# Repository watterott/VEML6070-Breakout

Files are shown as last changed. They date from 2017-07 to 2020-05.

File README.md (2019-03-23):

# VEML6070-Breakout
Breakout with Vishay VEML6070 digital UV Light Sensor.

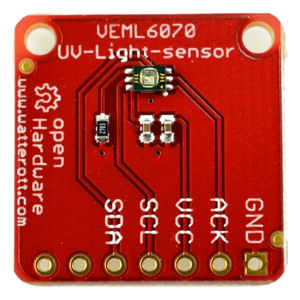
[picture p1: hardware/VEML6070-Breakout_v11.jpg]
VEML6070-Breakout


* [Vishay VEML6070](https://www.vishay.com/docs/84277/veml6070.pdf) Light Sensor
* Detects UV light
* TWI/I2C Interface (address 0x38 and 0x39)
* 3.3V - 5V Power Supply and Logic Level
* Open-Source and released under the [Creative Commons Attribution Share-Alike License](https://creativecommons.org/licenses/by-sa/4.0/).
* **[Documentation on learn.watterott.com](https://learn.watterott.com)**

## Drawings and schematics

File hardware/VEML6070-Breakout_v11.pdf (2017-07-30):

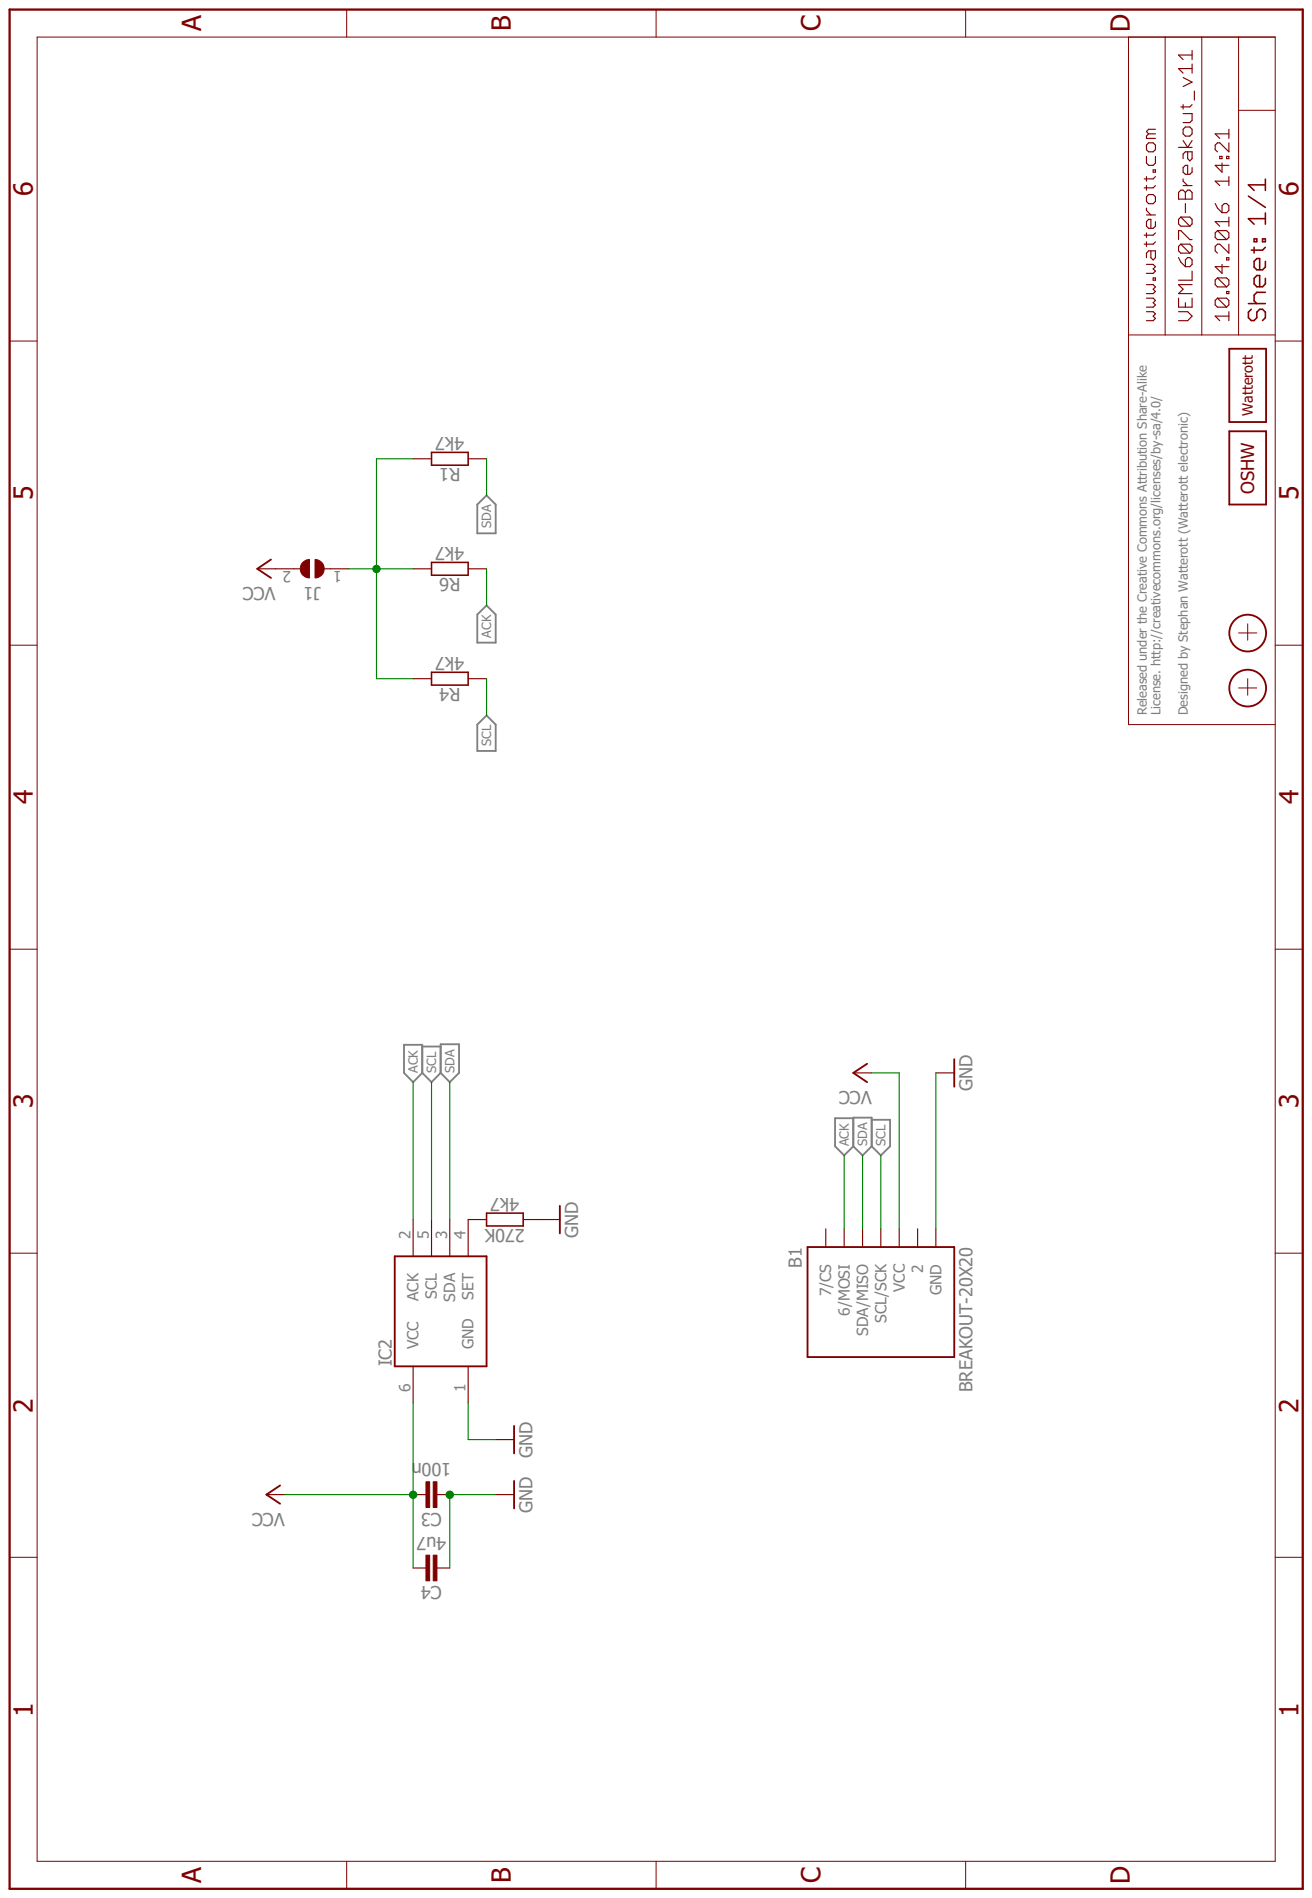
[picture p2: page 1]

GND GND GND CCV n0017k4 7k4 7k4 7k4 GND 7u4 CCV CCV Released under the Creative Commons Attribution Share-Alike License. http://creativecommons.org/licenses/by-sa/4.0/ Designed by Stephan Watterott (Watterott electronic) 3C1R4R6RGND 1 ACK 2 SDA 3 SET 4 SCL 5 VCC 6 IC2 K072 4C 1J 2 1 B1 BREAKOUT-20X20 6/MOSI SDA/MISO SCL/SCK VCC2 GND 7/CS SCL SCL SCL SDA SDA SDA ACK ACK ACK ABCD 1 2 3 4 5 6 ABCD 1 2 3 4 5 6 Watterott OSHW

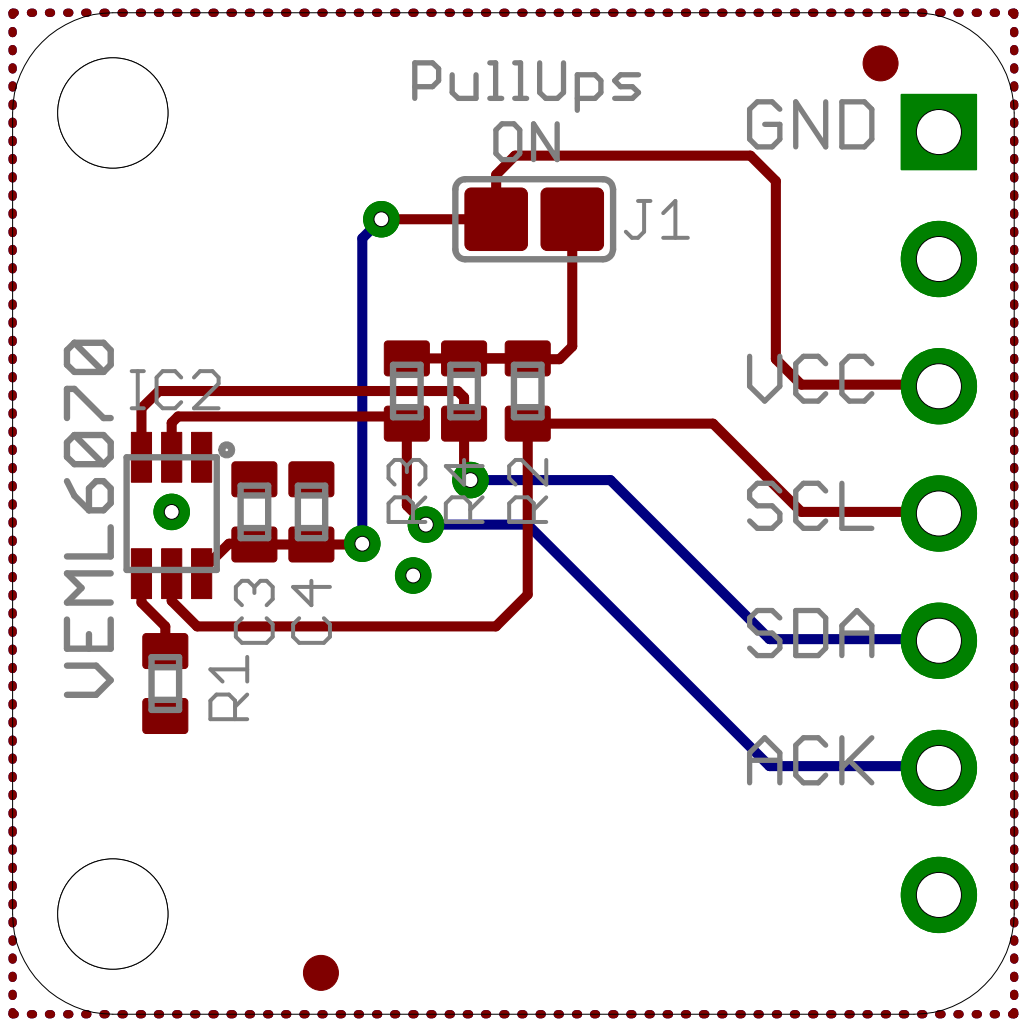
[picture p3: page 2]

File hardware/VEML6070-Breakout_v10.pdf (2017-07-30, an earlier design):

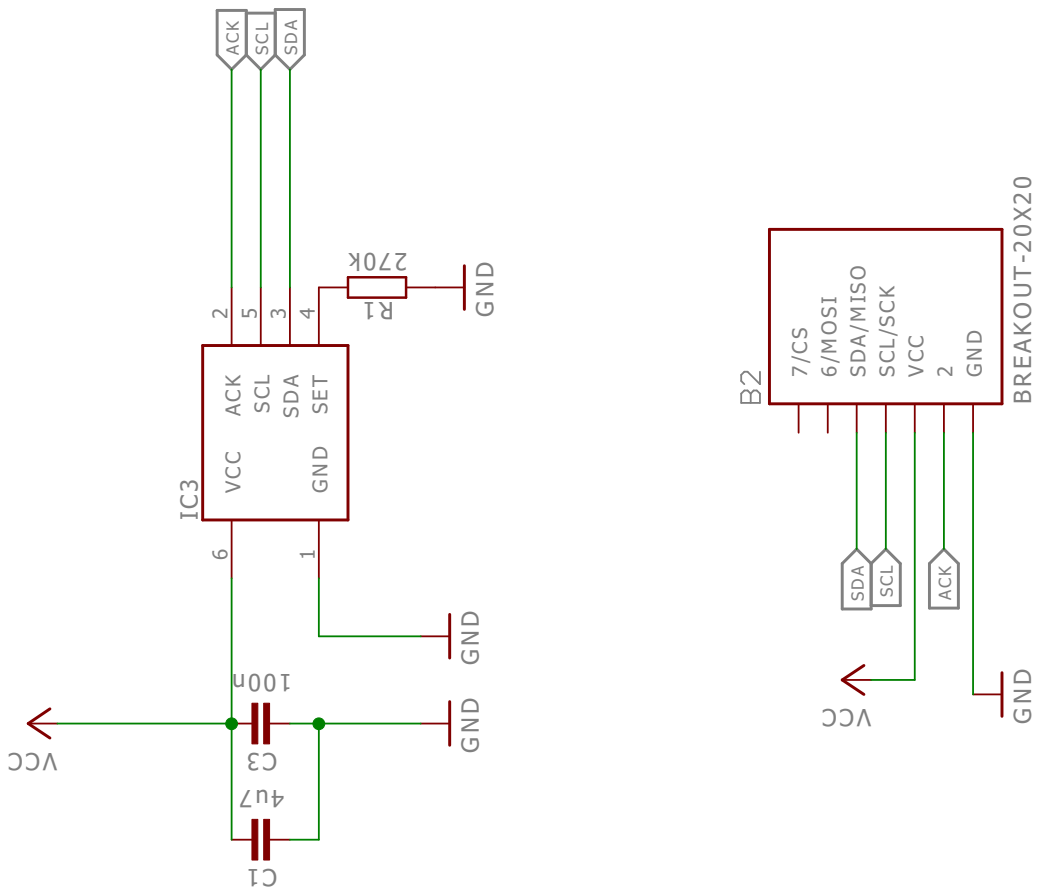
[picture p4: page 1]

GND GNDGND CCV n001 k 072 CCV 7u4 GND Released under the Creative Commons Attribution Share-Alike License http://creativecommons.org/licenses/by-sa/4.0/ Designed by Stephan W atterott (W atterott electronic) 3 C 1 R GND 1 ACK 2 SDA 3 SET 4 SCL 5 VCC 6 IC3 1 C BREAKOUT-20X20 6/MOSI SDA/MISO SCL/SCK VCC 2GND 7/CS SCL SCL SDA SDA ACK ACK ABCD 1 2 3 4 5 6 ABCD 1 2 3 4 5 6 OSHW

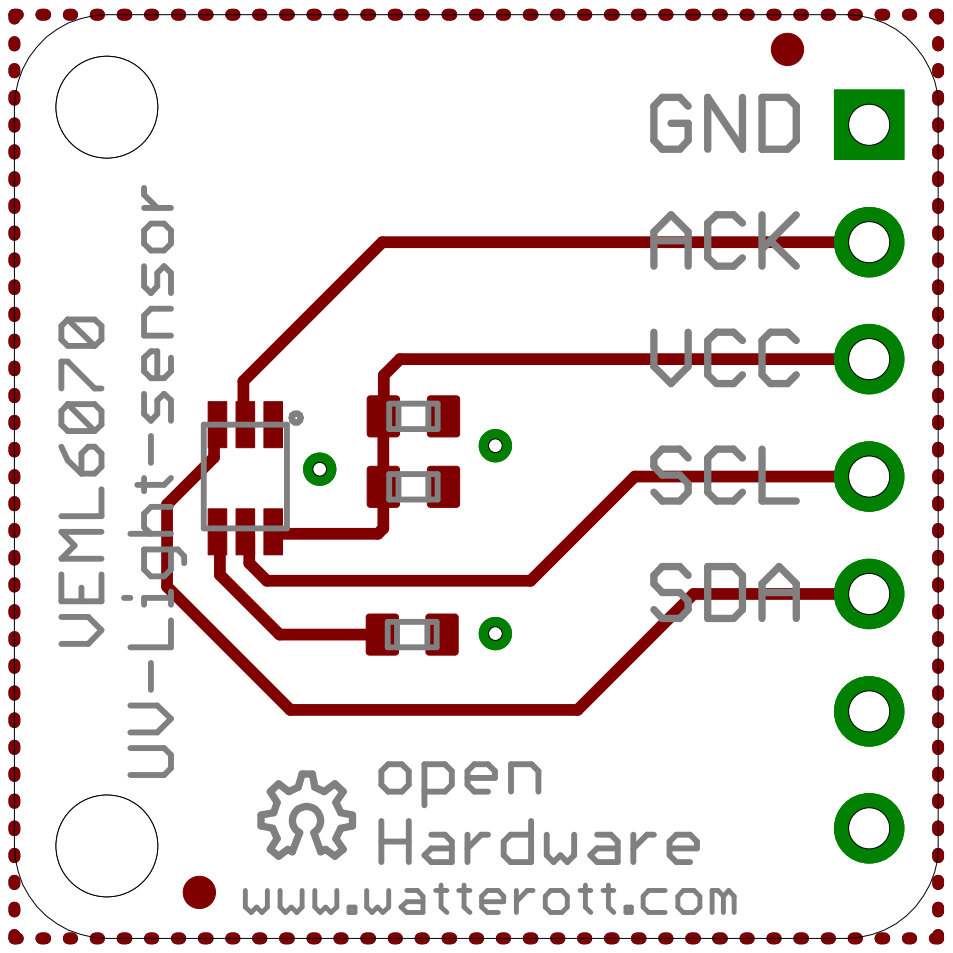
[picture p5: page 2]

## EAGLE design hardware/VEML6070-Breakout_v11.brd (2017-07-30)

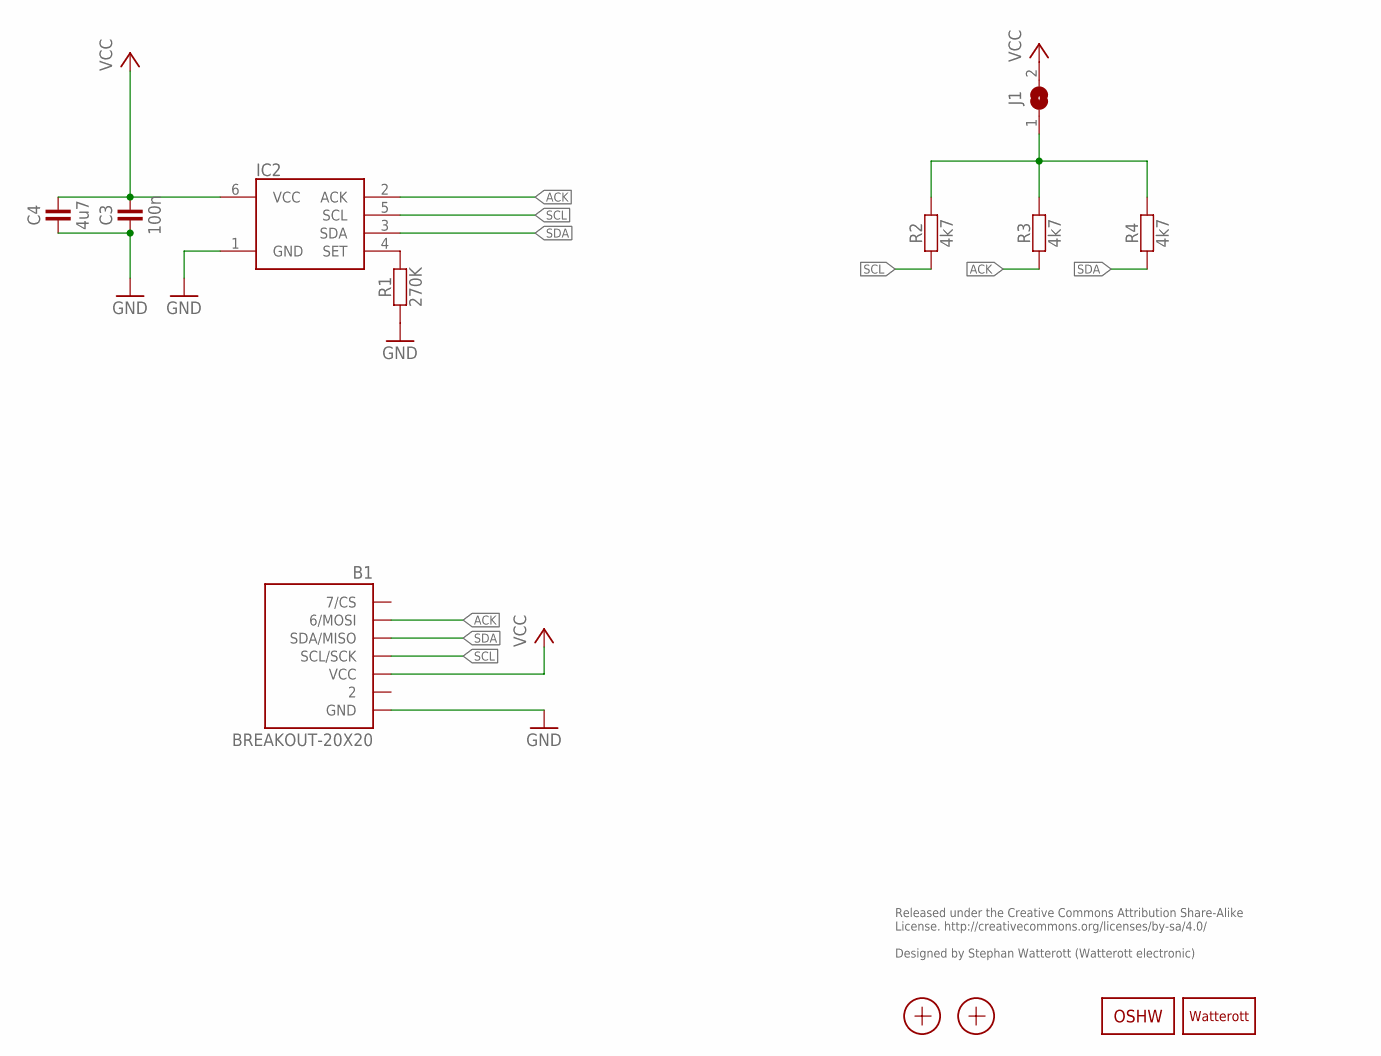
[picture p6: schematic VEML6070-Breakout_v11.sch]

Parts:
B1: BREAKOUT-20X20
C3: 100n; R0402
C4: 4u7; R0402
IC2: VEML6070; OPLGA
J1: JUMPER2-0603-NC; JUMPER2-0603_NC
LOGO1: LOGO-S_PLACE_M; SPARK_TPLACE_M
LOGO2: OSHW_LOGOX0070; OSHW_6X70
R1: 270K; R0402
R2, R3, R4: 4k7; R0402
X1, X2: PASSER-07; PASSER_07MM

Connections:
ACK: B1.MOSI (6/MOSI), IC2.2 (ACK), R3.1
GND: B1.GND, C3.1, C4.1, IC2.1 (GND), R1.1
unnamed: IC2.4 (SET), R1.2
unnamed: J1.1, R2.2, R3.2, R4.2
SCL: B1.SCL/SCK, IC2.5 (SCL), R2.1
SDA: B1.SDA/MISO, IC2.3 (SDA), R4.1
VCC: B1.VCC, C3.2, C4.2, IC2.6 (VCC), J1.2

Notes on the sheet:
Released under the Creative Commons Attribution Share-Alike License. http://creativecommons.org/licenses/by-sa/4.0/ Designed by Stephan Watterott (Watterott electronic)

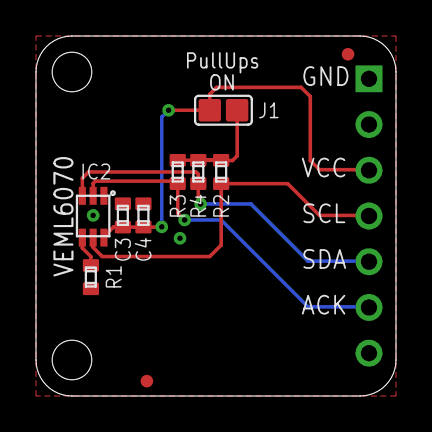
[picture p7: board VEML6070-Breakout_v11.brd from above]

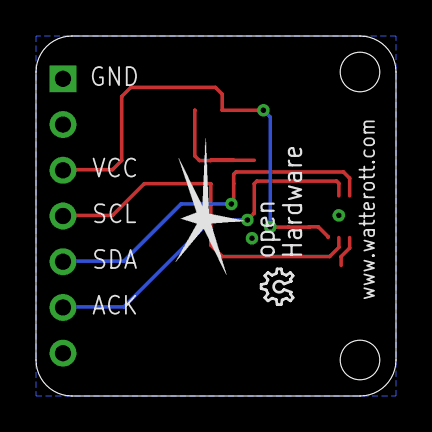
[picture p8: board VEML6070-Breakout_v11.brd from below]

Board: 2 copper layers, 20.0 x 20.0 mm, 13 parts (2 on the bottom side), 7 nets.

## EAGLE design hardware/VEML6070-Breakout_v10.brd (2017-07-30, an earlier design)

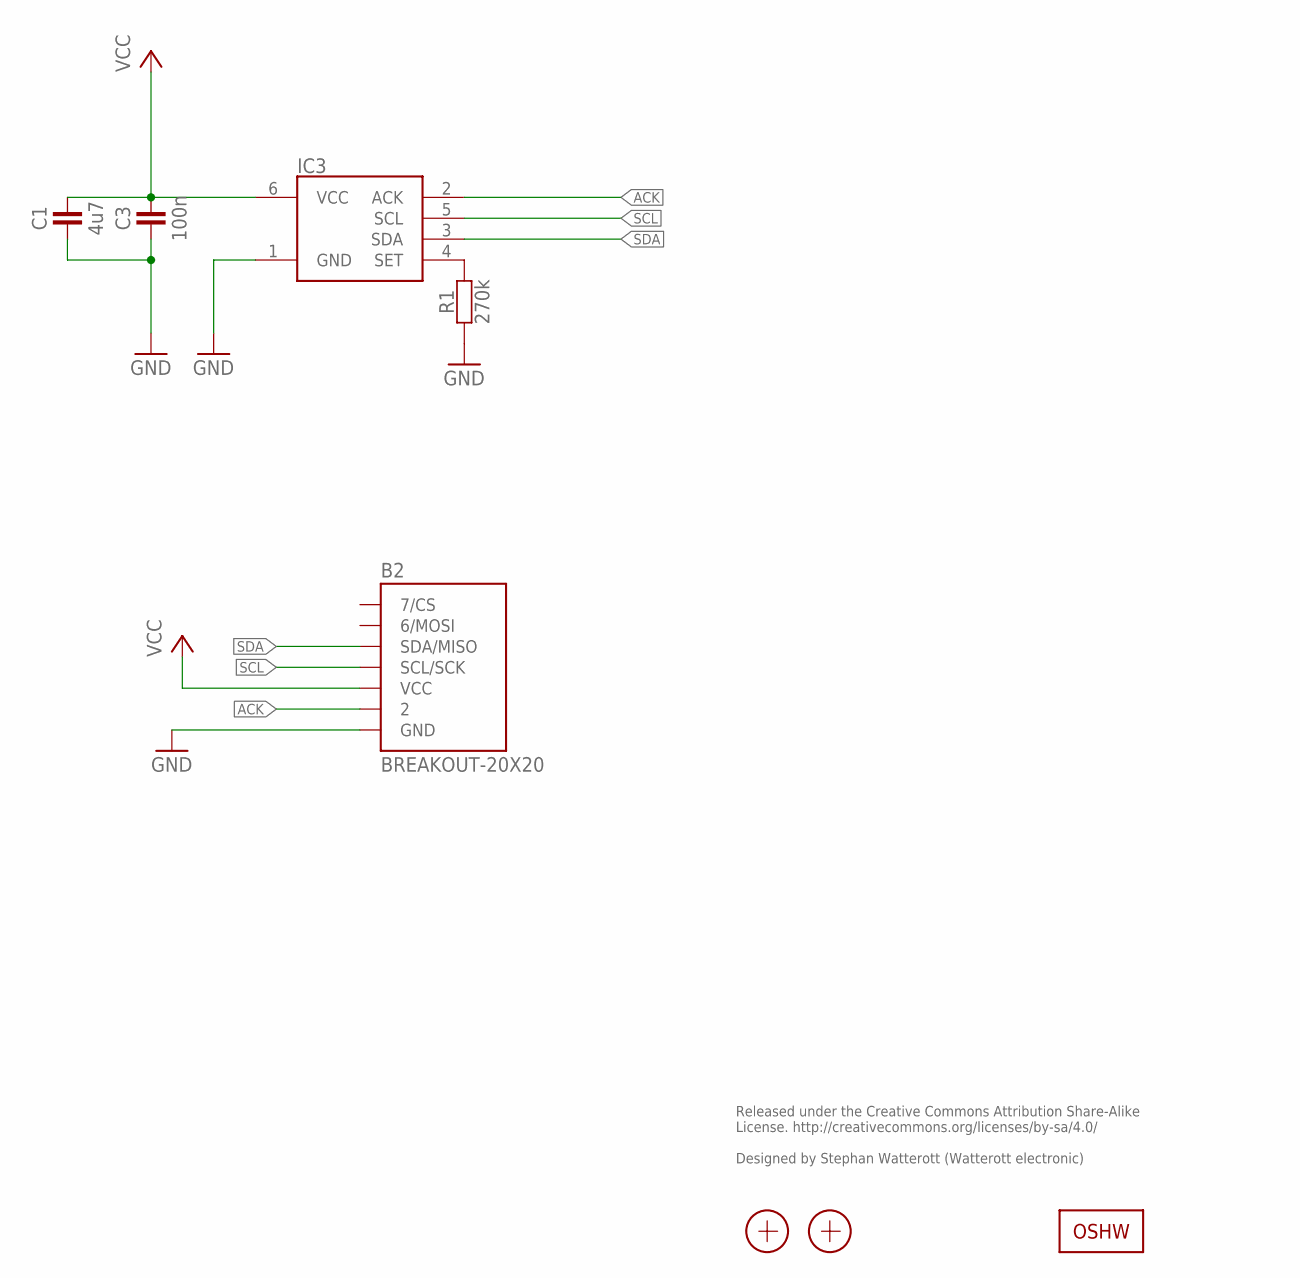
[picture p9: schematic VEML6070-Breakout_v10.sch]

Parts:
B2: BREAKOUT-20X20
C1: 4u7; R0402
C3: 100n; R0402
IC3: VEML6070; OPLGA
LOGO2: OSHW_LOGOX0070; OSHW_6X70
R1: 270k; R0402
X1, X2: PASSER-07; PASSER_07MM

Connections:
ACK: B2.2, IC3.2 (ACK)
GND: B2.GND, C1.1, C3.1, IC3.1 (GND), R1.1
unnamed: IC3.4 (SET), R1.2
SCL: B2.SCL/SCK, IC3.5 (SCL)
SDA: B2.SDA/MISO, IC3.3 (SDA)
VCC: B2.VCC, C1.2, C3.2, IC3.6 (VCC)

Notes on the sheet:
Released under the Creative Commons Attribution Share-Alike License. http://creativecommons.org/licenses/by-sa/4.0/ Designed by Stephan Watterott (Watterott electronic)

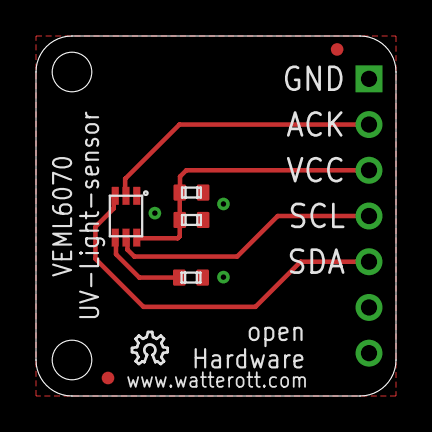
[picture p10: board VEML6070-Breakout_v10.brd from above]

Board: 2 copper layers, 20.0 x 20.0 mm, 8 parts (0 on the bottom side), 6 nets.

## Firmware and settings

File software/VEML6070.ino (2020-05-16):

/*
  Example sketch for VEML6070-Breakout (Digital UV Light Sensor).
  Rset=270k on breakout, UVA sensitivity: 5.625 uW/cm²/step

  Board           I2C/TWI Pins
                  SDA, SCL
  ----------------------------
  Uno, Ethernet    A4, A5
  Mega             20, 21
  Leonardo          2,  3
  Due              20, 21

  Integration Times and UVA Sensitivity:
    Rset=240k -> 1T=100.0ms ->   5.000 uW/cm²/step
    Rset=270k -> 1T=112.5ms ->   5.625 uW/cm²/step
    Rset=300k -> 1T=125.0ms ->   6.250 uW/cm²/step
    Rset=600k -> 1T=250.0ms ->  12.500 uW/cm²/step

  Example source code free to use.
  Further information: https://learn.watterott.com/license/
*/

#include <Wire.h>

#define I2C_ADDR 0x38 //0x38 and 0x39

//Integration Time
#define IT_1_2 0x0 //1/2T
#define IT_1   0x1 //1T
#define IT_2   0x2 //2T
#define IT_4   0x3 //4T

void setup()
{
  Serial.begin(9600);
  while(!Serial); //wait for serial port to connect (needed for Leonardo only)

  Wire.begin();

  Wire.beginTransmission(I2C_ADDR);
  Wire.write((IT_1<<2) | 0x02);
  Wire.endTransmission();
  delay(500);
}

void loop()
{
  byte msb=0, lsb=0;
  uint16_t uv;

  Wire.requestFrom(I2C_ADDR+1, 1); //MSB
  delay(1);
  if(Wire.available())
    msb = Wire.read();

  Wire.requestFrom(I2C_ADDR+0, 1); //LSB
  delay(1);
  if(Wire.available())
    lsb = Wire.read();

  uv = (msb<<8) | lsb;
  Serial.println(uv, DEC); //output in steps (16bit)

  delay(1000);
}
